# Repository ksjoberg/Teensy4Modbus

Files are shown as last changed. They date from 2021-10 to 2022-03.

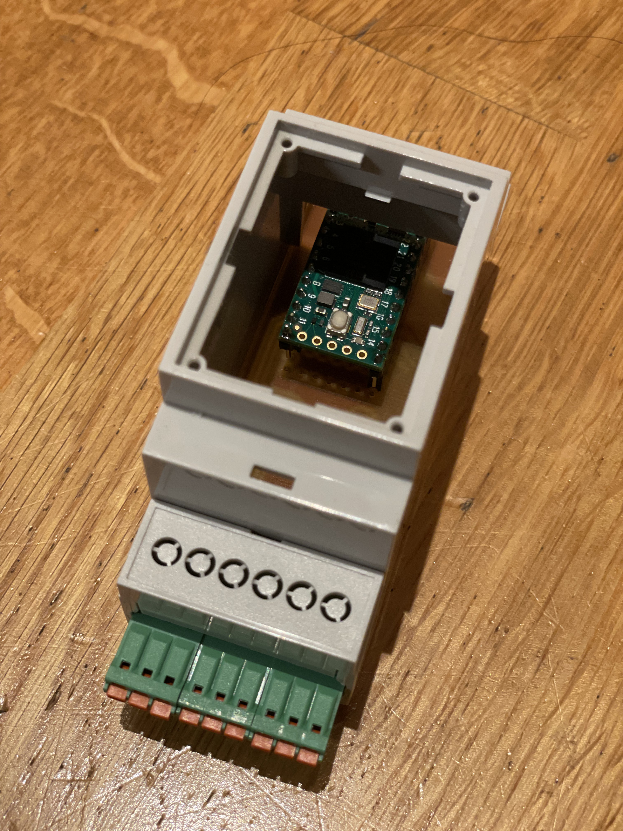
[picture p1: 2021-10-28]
pcb/IMG_4391.JPG

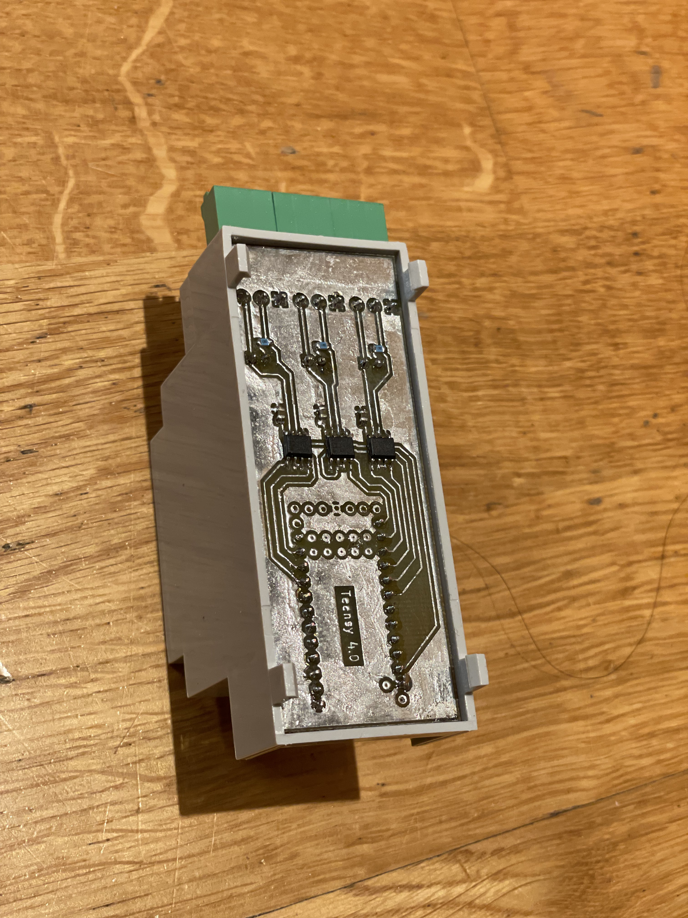
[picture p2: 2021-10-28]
pcb/IMG_4390.JPG

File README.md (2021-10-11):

# Teensy4Modbus

This application uses the CDC-ECM mode implemented in the Teensy Cores fork at https://github.com/ksjoberg/cores/tree/teensy4-ecm to expose the Teensy as a network device to a computer.

The vision is to add a ModbusTCP listener so that the Teensy can act as a ModbusTCP to ModbusRTU gateway using one or more of its seven hardware serial ports.

The inspiration sprung out of the fact that PyModbus can't properly participate on a Modbus serial bus with the RTU protocol: the framing information is lost as the serial port exposes the bus as a stream of bytes. The RTU frames are defined as being preceeded by a 3.5 char time silence on the bus, but the usermode applications usually just calls the serial port read function to to fill a provided buffer. This read call bridges the inter-frame bus silence and may returns multiple partial frames in one read.

ModbusTCP handles the framing correctly, so if PyModbus can talk to a ModbusTCP device instead it will work as intended.

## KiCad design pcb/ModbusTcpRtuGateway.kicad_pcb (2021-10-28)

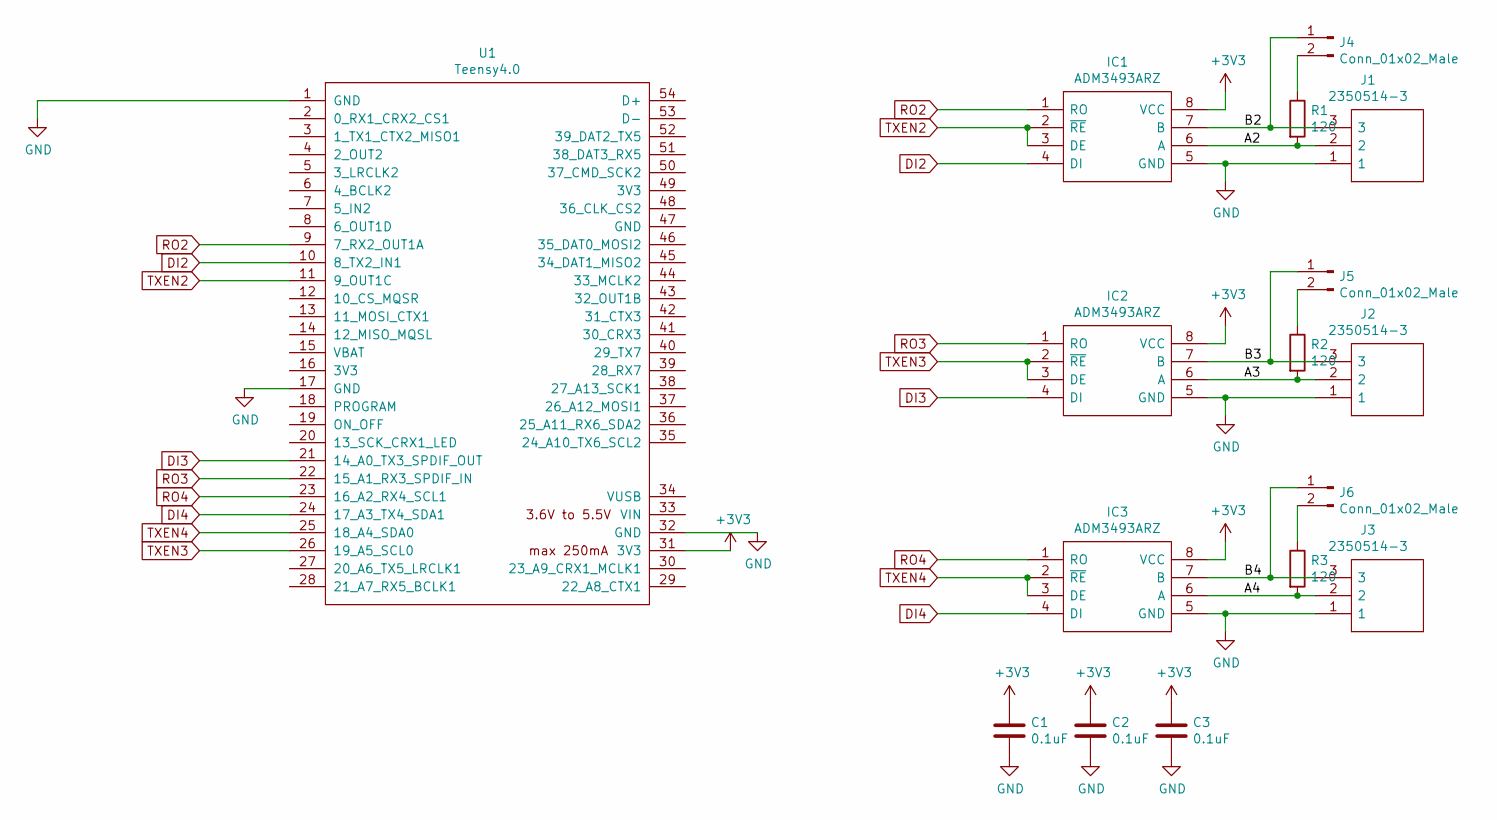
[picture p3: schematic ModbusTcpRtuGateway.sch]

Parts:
C1, C2, C3: 0.1uF; C_0805_2012Metric_Pad1.18x1.45mm_HandSolder
IC1, IC2, IC3: ADM3493ARZ; SOIC127P600X175-8N; Mouser Part Number 584-ADM3493ARZ
J1, J2, J3: 2350514-3; SHDRRA3W90P0X350_1X3_1110X920X691P; Manufacturer_Part_Number 2350514-3; Mouser Part Number 571-2350514-3
J4, J5, J6: Conn_01x02_Male; PinHeader_1x02_P2.54mm_Vertical
R1, R2, R3: 120; R_0603_1608Metric_Pad0.98x0.95mm_HandSolder
U1: Teensy4.0; Teensy40

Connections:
+3V3: C1.1, C2.1, C3.1, IC1.8 (VCC), IC2.8 (VCC), IC3.8 (VCC), U1.31 (3V3)
/A2: IC1.6 (A), J1.2, R1.2
/A3: IC2.6 (A), J2.2, R2.2
/A4: IC3.6 (A), J3.2, R3.2
/B2: IC1.7 (B), J1.3, J4.1
/B3: IC2.7 (B), J2.3, J5.1
/B4: IC3.7 (B), J3.3, J6.1
DI2: IC1.4 (DI), U1.10 (8_TX2_IN1)
DI3: IC2.4 (DI), U1.21 (14_A0_TX3_SPDIF_OUT)
DI4: IC3.4 (DI), U1.24 (17_A3_TX4_SDA1)
GND: C1.2, C2.2, C3.2, IC1.5 (GND), IC2.5 (GND), IC3.5 (GND), J1.1, J2.1, J3.1, U1.1 (GND), U1.17 (GND), U1.32 (GND)
unnamed: J4.2, R1.1
unnamed: J5.2, R2.1
unnamed: J6.2, R3.1
RO2: IC1.1 (RO), U1.9 (7_RX2_OUT1A)
RO3: IC2.1 (RO), U1.22 (15_A1_RX3_SPDIF_IN)
RO4: IC3.1 (RO), U1.23 (16_A2_RX4_SCL1)
TXEN2: IC1.2 (~RE), IC1.3 (DE), U1.11 (9_OUT1C)
TXEN3: IC2.2 (~RE), IC2.3 (DE), U1.26 (19_A5_SCL0)
TXEN4: IC3.2 (~RE), IC3.3 (DE), U1.25 (18_A4_SDA0)

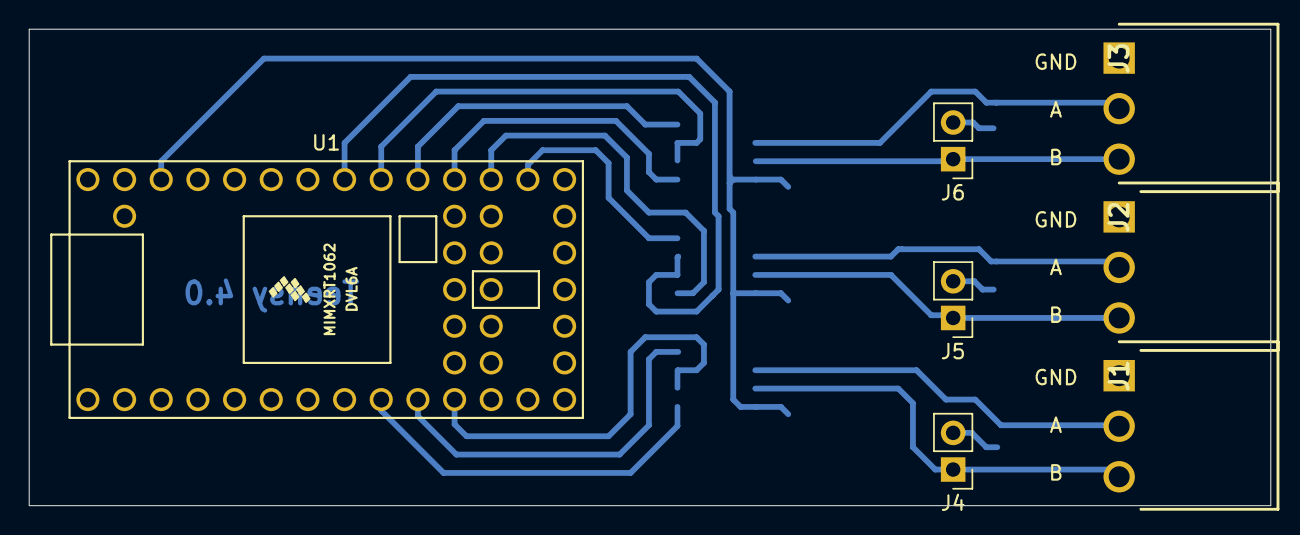
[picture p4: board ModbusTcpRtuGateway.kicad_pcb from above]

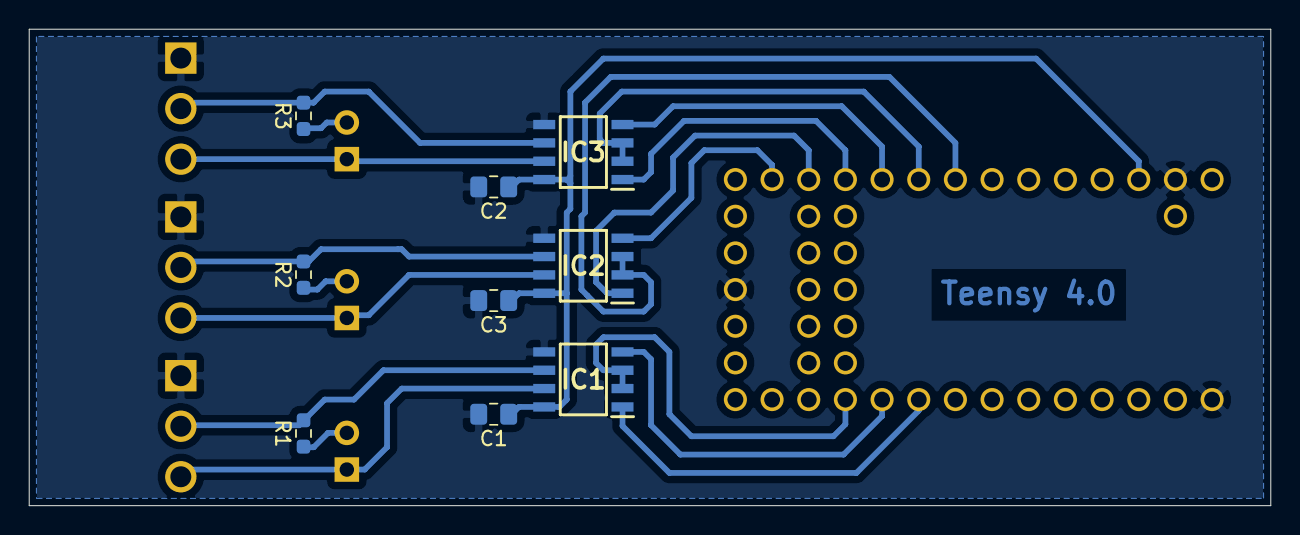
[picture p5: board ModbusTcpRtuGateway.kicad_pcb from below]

Board: 2 copper layers, 86.0 x 33.0 mm, 16 parts (9 on the bottom side), 20 nets.

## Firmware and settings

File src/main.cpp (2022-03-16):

#include <Arduino.h>
#include "core_pins.h"
#include "debug/printf.h"
#include "usb_ecm.h"

#include "dhserver.h"
//#include "dnserver.h"
#include "netif/etharp.h"
#include "lwip/init.h"
#include "lwip/netif.h"
#include "lwip/pbuf.h"
#include "lwip/icmp.h"
#include "lwip/udp.h"
#include "lwip/opt.h"
#include "lwip/arch.h"
#include "lwip/api.h"
#include "lwip/inet.h"
#include "lwip/dns.h"
#include "lwip/tcp.h"
#include "lwip/sys.h"
#include "lwip/timeouts.h"

#include "serialmenu.h"

#include "configuration.h"
#include "modbus_tcp_rtu.h"

ModbusTcpRtu rtugws[MODBUS_GW_COUNT] = {
  ModbusTcpRtu(&Serial2, 9, "X", &Serial),
  ModbusTcpRtu(&Serial3, 19, "Y", &Serial),
  ModbusTcpRtu(&Serial4, 18, "Z", &Serial)
};

void serialEvent2()
{
  rtugws[0].serialEvent();
}

void serialEvent3()
{
  rtugws[1].serialEvent();
}

void serialEvent4()
{
  rtugws[2].serialEvent();
}

#define ARRAY_SIZE(x)   (sizeof(x) / sizeof(*x))

static struct netif netif_data;
static const ip_addr_t ipaddr  = IPADDR4_INIT_BYTES(192, 168, 7, 1);
static const ip_addr_t netmask = IPADDR4_INIT_BYTES(255, 255, 255, 0);
static const ip_addr_t gateway = IPADDR4_INIT_BYTES(0, 0, 0, 0);
static struct pbuf *received_frame;

static dhcp_entry_t entries[] =
{
    /* mac ip address                          lease time */
    { {0}, IPADDR4_INIT_BYTES(192, 168, 7, 2), 24 * 60 * 60 },
    { {0}, IPADDR4_INIT_BYTES(192, 168, 7, 3), 24 * 60 * 60 },
    { {0}, IPADDR4_INIT_BYTES(192, 168, 7, 4), 24 * 60 * 60 },
};

static const dhcp_config_t dhcp_config =
{
    .router = IPADDR4_INIT_BYTES(0, 0, 0, 0),  /* router address (if any) */
    .port = 67,                                /* listen port */
    .dns = IPADDR4_INIT_BYTES(192, 168, 7, 1), /* dns server (if any) */
    "sam",                                     /* dns suffix */
    ARRAY_SIZE(entries),                       /* num entry */
    entries                                    /* entries */
};

err_t output_fn(struct netif *netif, struct pbuf *p, const ip_addr_t *ipaddr)
{
  return etharp_output(netif, p, ipaddr);
}

static void usb_ecm_transmit_packet(struct pbuf *p)
{
  struct pbuf *q;
  size_t buf_size;

  while(!usb_ecm_can_transmit()) yield();
  char *buf = (char*)usb_ecm_write_start(&buf_size);
  char *buf_end = buf + buf_size;
  for(q = p; q != NULL; q = q->next)
  {

    //char printbuf[3];
    //for(size_t i=0; i<q->len; i++)
    //{
    //  sprintf((char*)&printbuf, "%02x", ((char *)q->payload)[i]);
    //  printf((const char*)&printbuf);
    //}

    u16_t seglen = q->len;
    while(seglen)
    {
      size_t to_copy = buf + seglen > buf_end ? buf_end - buf : seglen;
      memcpy(buf, (char*)q->payload + (q->len - seglen), to_copy);
      buf += to_copy;
      seglen -= to_copy;
      if (buf == buf_end)
      {
        usb_ecm_write_done(buf_size); // Entire buffer is filled
        while(!usb_ecm_can_transmit()) yield();
        buf = (char*)usb_ecm_write_start(&buf_size);
        buf_end = buf + buf_size;
      }
    }

    if (q->tot_len == q->len) break;
  }
  size_t last_size = buf - (buf_end - buf_size);
  usb_ecm_write_done(last_size);
}

err_t linkoutput_fn(struct netif *netif, struct pbuf *p)
{
    for (;;)
    {
        if (usb_ecm_can_transmit()) goto ok_to_xmit;
        yield();
        sys_check_timeouts();
    }

    return ERR_USE;

ok_to_xmit:
    usb_ecm_transmit_packet(p);

    return ERR_OK;
}

err_t netif_init_cb(struct netif *netif)
{
    LWIP_ASSERT("netif != NULL", (netif != NULL));
    netif->mtu = ECM_MTU;
    netif->flags = NETIF_FLAG_BROADCAST | NETIF_FLAG_ETHARP | NETIF_FLAG_LINK_UP | NETIF_FLAG_UP;
    netif->state = NULL;
    netif->name[0] = 'E';
    netif->name[1] = 'X';
    netif->linkoutput = linkoutput_fn;
    netif->output = output_fn;
    return ERR_OK;
}

void init_lwip()
{
    struct netif  *netif = &netif_data;

    lwip_init();
    netif->hwaddr_len = 6;
    memcpy(netif->hwaddr, (u_int8_t*)&HW_OCOTP_MAC0, 6);

    netif = netif_add(netif, &ipaddr, &netmask, &gateway, NULL, netif_init_cb, ip_input);
    netif_set_default(netif);
}

void setup() {
  // put your setup code here, to run once:
  pinMode(13, OUTPUT);

  digitalWriteFast(13, HIGH);
  delay(500);
  digitalWriteFast(13, LOW);
  delay(500);


  while (!usb_configuration) yield();
  delay(2500);
  if (CrashReport)
  {
    CrashReport.printTo(Serial);
  }
  configuration_load();
  for(uint8_t i=0; i<MODBUS_GW_COUNT; i++)
  {
    rtugws[i].configure(active_config.modbus_gw[i].ipaddress, active_config.modbus_gw[i].tcp_port, active_config.modbus_gw[i].unit_filter);
    rtugws[i].setFlags(active_config.modbus_gw[i].flags);
  }

  MenuSetup();
  init_lwip();

  while (!netif_is_up(&netif_data)) loop();

  if (active_config.dhcps_enabled)
  {
    while (dhserv_init(&dhcp_config) != ERR_OK) loop();
  }

  for(uint8_t i=0; i<MODBUS_GW_COUNT; i++)
  {
    rtugws[i].begin(active_config.modbus_gw[i].baudrate);
  }
  //while (dnserv_init(&ipaddr, 53, dns_query_proc) != ERR_OK);
}

void loop() {
  // put your main code here, to run repeatedly:
  size_t len;
  const void* packet = usb_ecm_read(&len);
  if (packet != NULL)
  {
    //printf("got packet with length %x\n", len);
    //char buf[3];
    //unsigned char *p = (unsigned char*)packet;
    //for(size_t i=0; i<len; i++)
    //{
    //  sprintf((char*)&buf, "%02x", p[i]);
    //  printf((const char*)&buf);
    //}
    //printf("\n");

    received_frame = pbuf_alloc(PBUF_RAW, len, PBUF_POOL);
    if (!received_frame) 
      return;

    memcpy(received_frame->payload, packet, len);
    ethernet_input(received_frame, &netif_data);
    usb_ecm_read_done();
  }
  sys_check_timeouts();

  yield();
  MenuPoll();
  for(uint8_t i=0; i<MODBUS_GW_COUNT; i++)
  {
    rtugws[i].doYield();
    rtugws[i].setFlags(active_config.modbus_gw[i].flags);
  }
}


int main(void)
{
  setup();
  while(1)
  {
    loop();
  }
}

/* lwip has provision for using a mutex, when applicable */
sys_prot_t sys_arch_protect(void)
{
  return 0;
}
void sys_arch_unprotect(sys_prot_t pval)
{
  (void)pval;
}

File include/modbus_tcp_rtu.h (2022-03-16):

#ifndef modbus_tcp_rtu_h
#define modbus_tcp_rtu_h

#include "HardwareSerial.h"
#include "lwip/tcp.h"

#ifdef __cplusplus
extern "C" {
#endif
#define MODBUS_RTU_FRAME_SIZE   256
#define MODBUS_MAX_TCP_CONNECTIONS 4

enum MODBUSTCPRTU_FLAGS {
    DEBUG_RTU   = 0x01,
    DEBUG_TCP   = 0x02
};

struct modbus_gw_counters {
    uint32_t rtu_rx_frames_dropped_badlen;
    uint32_t rtu_rx_frames_dropped_badcrc;
    uint32_t rtu_rx_frames_dropped_notforme;
    uint32_t rtu_rx_frames_dropped_notcp;
    uint32_t rtu_rx_frames;
    uint32_t rtu_tx_frames;
    uint32_t rtu_rx_bytes;
    uint32_t rtu_tx_bytes;
    uint32_t tcp_rx_frames;
    uint32_t tcp_tx_frames;
    uint32_t tcp_rx_bytes;
    uint32_t tcp_tx_bytes;
};

class ModbusTcpRtu
{
private:
    void checkFrameReady(bool serialEvent = false);
    void processRtuFrame();
public:
	constexpr ModbusTcpRtu(
        HardwareSerial *serial_device,
        uint8_t tx_enable_pin,
        const char* name,
        Stream *debug_stream) :
        serialdev(serial_device),
        name(name),
        debug_stream(debug_stream),
        tx_enable_pin_(tx_enable_pin)
    { }
	void configure(uint32_t ipaddress, uint16_t tcp_port, const uint8_t* rtu_slave_ids);
    void setFlags(uint8_t flags);
	void begin(uint32_t baud, uint16_t format=0);
	void end(void);
	void serialEvent(void);
	void doYield(void);
    
	void clientConnectionFailed(void);

	operator bool()			{ return true; }

    bool            outstanding_transaction = false;
    uint16_t        current_transaction = 0;
    struct tcp_pcb* active_pcb = nullptr;
    struct modbus_gw_counters counters = { 0 };
	HardwareSerial * const serialdev;
    const char*     name = nullptr;
    Stream*         debug_stream;
    uint8_t         debug_flags = 0;
private:
	uint8_t			tx_enable_pin_ = 0x0;
    uint32_t        last_serial_event = 0;
    uint32_t        frame_spacing = 0;
	ip4_addr		ip_address_ = { .addr = IPADDR_ANY };
	uint16_t		tcp_port_ = 0;
    const uint8_t*  rtu_slave_ids_ = nullptr;
    volatile uint8_t rtu_rx_buffer1[MODBUS_RTU_FRAME_SIZE] = { 0 };
    volatile uint8_t rtu_rx_buffer2[MODBUS_RTU_FRAME_SIZE] = { 0 };
    volatile uint8_t* rtu_rx_current = nullptr;
    size_t          rtu_rx_pos = 0;

    uint8_t *rtu_rx_frame = 0;
    size_t rtu_rx_frame_len = 0;
    struct tcp_pcb *main_pcb = 0;
    uint32_t        connection_failed_at = 0;

	void clientConnect(void);
    friend err_t server_recv(void *arg, struct tcp_pcb *pcb, struct pbuf *p, err_t err);
};

#ifdef __cplusplus
}
#endif
#endif // modbus_tcp_rtu_h

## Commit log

2021-10-21 Add RTU slave capability
    [configuration.h]
2021-10-28 PCB initial (no submodule)
    [ModbusTcpRtuGateway.kicad_pcb, ModbusTcpRtuGateway.sch]
2022-03-16 Code cleanup
    [configuration.h]
